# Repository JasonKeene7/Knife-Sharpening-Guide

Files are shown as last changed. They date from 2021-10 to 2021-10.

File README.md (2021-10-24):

# Knife-Sharpening-Guide
An Arduino based project to assist in keeping a consistent grinding angle.

Having recently finished building, setting up, and toubleshooting my PC, I figured starting a neew project should be my next step. Get to prevent my electronics skills from getting rusty, find all the productivity programs I need to install, and to curb my abject and growing bordem.

On the side, I was also learning my way around the kitchen which of course includes keeping all the knives sharp. Noticed they began dulling, so I took out my grindstone set hoping to rehone the edges; grind, wash, grind, wash, repeat, repeat, paper test… still made the cut, but not as smooth as I hoped and as I already done after a previous session. Huh…. Had a good, disatisfied peer down along the edge, the light just about catch the bevel’s curvature. Go figue I messed up my grinding angle, damn thing is suppoded to be flat….

“Why not make something calculate the angle for you?” rightly spoke the engineer in the back of my mind. “All I needed was to display the tilt of the knife somehow, it will be a fun warmup!”

The project lasted from the April 20th 2021 to the October 11th 2021: total project time 15 days and .72 hours.

Heads up. I am not a good essay writer, so kindly forgive any amature mistakes.

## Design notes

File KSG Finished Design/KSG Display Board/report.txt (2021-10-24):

Plot file "/run/media/jasonk/4119-0B9F/Jason Keene/Productivity/Electronics/KiCad/KSG Display Board/KSG Display Board-F_Cu.gbr" created.
Plot file "/run/media/jasonk/4119-0B9F/Jason Keene/Productivity/Electronics/KiCad/KSG Display Board/KSG Display Board-B_Cu.gbr" created.
Plot file "/run/media/jasonk/4119-0B9F/Jason Keene/Productivity/Electronics/KiCad/KSG Display Board/KSG Display Board-F_Paste.gbr" created.
Plot file "/run/media/jasonk/4119-0B9F/Jason Keene/Productivity/Electronics/KiCad/KSG Display Board/KSG Display Board-B_Paste.gbr" created.
Plot file "/run/media/jasonk/4119-0B9F/Jason Keene/Productivity/Electronics/KiCad/KSG Display Board/KSG Display Board-F_SilkS.gbr" created.
Plot file "/run/media/jasonk/4119-0B9F/Jason Keene/Productivity/Electronics/KiCad/KSG Display Board/KSG Display Board-B_SilkS.gbr" created.
Plot file "/run/media/jasonk/4119-0B9F/Jason Keene/Productivity/Electronics/KiCad/KSG Display Board/KSG Display Board-F_Mask.gbr" created.
Plot file "/run/media/jasonk/4119-0B9F/Jason Keene/Productivity/Electronics/KiCad/KSG Display Board/KSG Display Board-B_Mask.gbr" created.
Plot file "/run/media/jasonk/4119-0B9F/Jason Keene/Productivity/Electronics/KiCad/KSG Display Board/KSG Display Board-Edge_Cuts.gbr" created.
Create Gerber job file "/run/media/jasonk/4119-0B9F/Jason Keene/Productivity/Electronics/KiCad/KSG Display Board/KSG Display Board-job.gbrjob"

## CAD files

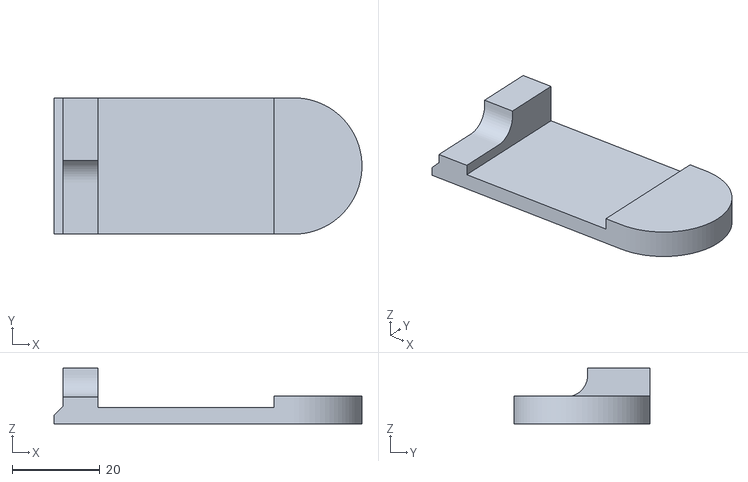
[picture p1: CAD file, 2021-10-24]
KSG Finished Design/3D Models/BNO Stand.stl
70.0 x 31.0 x 12.7

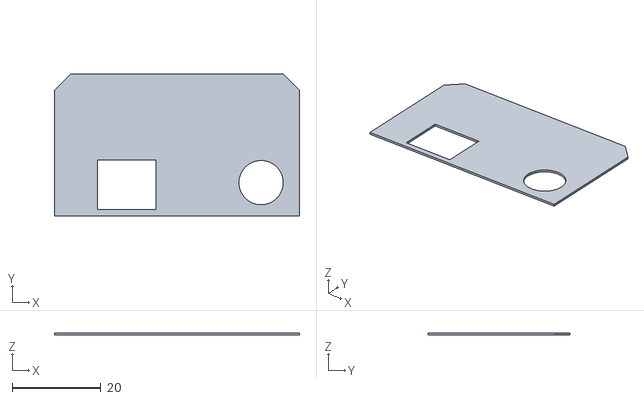
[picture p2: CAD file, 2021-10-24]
KSG Finished Design/3D Models/Power Gate.stl
55.3 x 32.0 x 0.5

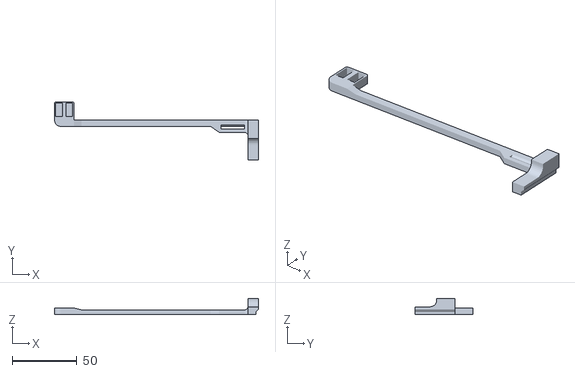
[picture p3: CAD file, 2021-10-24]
KSG Finished Design/3D Models/Clamp.stl
158.0 x 45.0 x 12.7

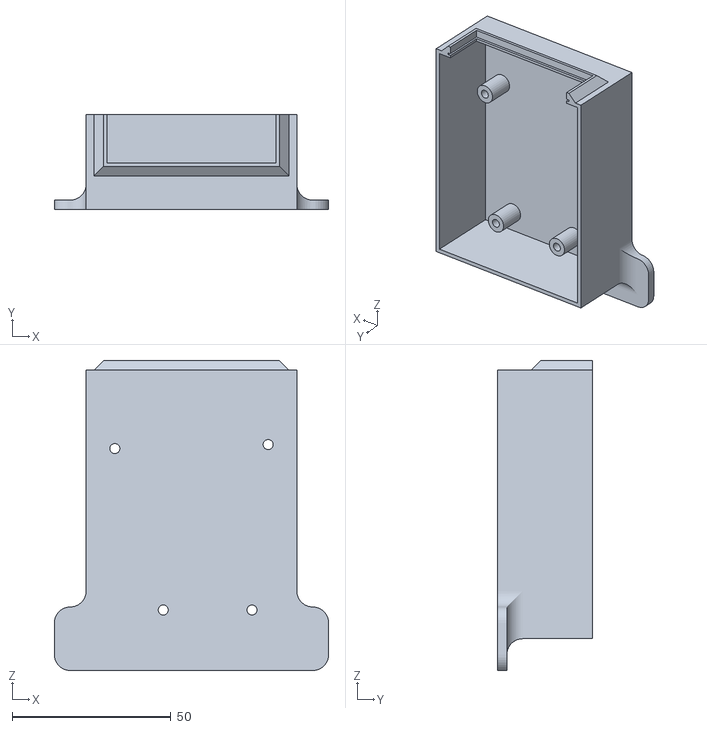
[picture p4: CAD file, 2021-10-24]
KSG Finished Design/3D Models/Case Bottom.stl
86.3 x 30.0 x 97.6

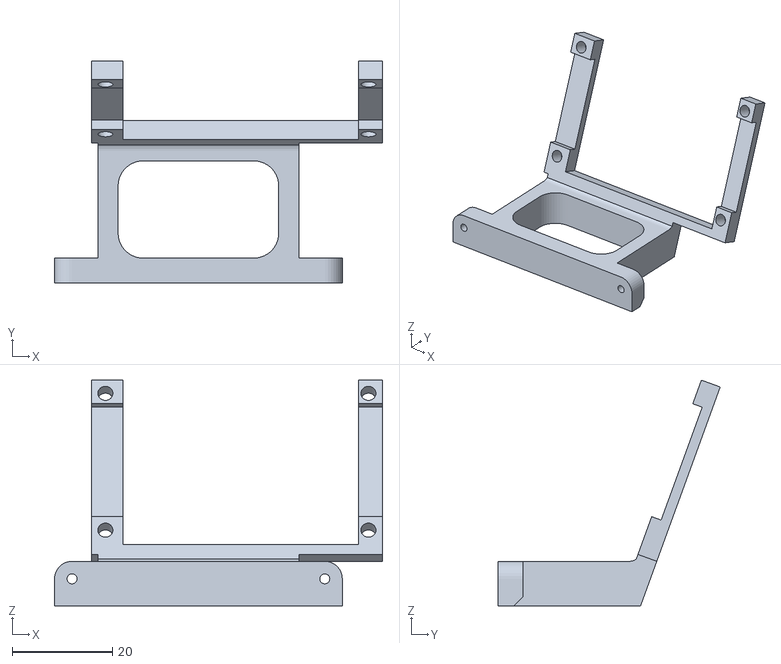
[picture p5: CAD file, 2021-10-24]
KSG Finished Design/3D Models/LCD Clamp.stl
65.3 x 44.3 x 45.0

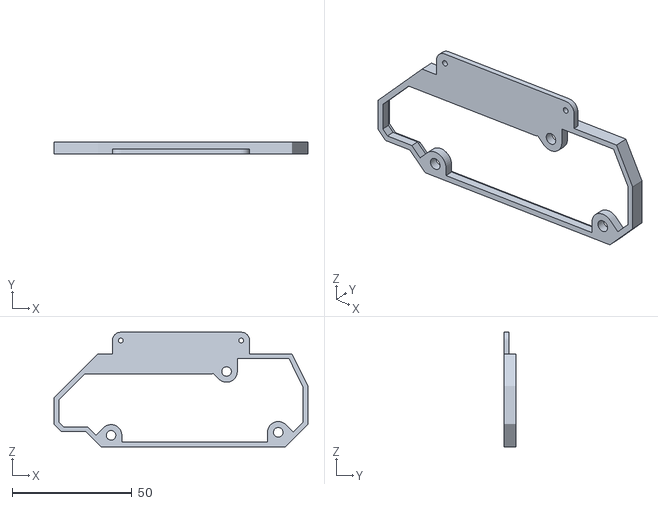
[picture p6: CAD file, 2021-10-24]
KSG Finished Design/3D Models/Control Pannel Plate.stl
106.1 x 5.00 x 47.9

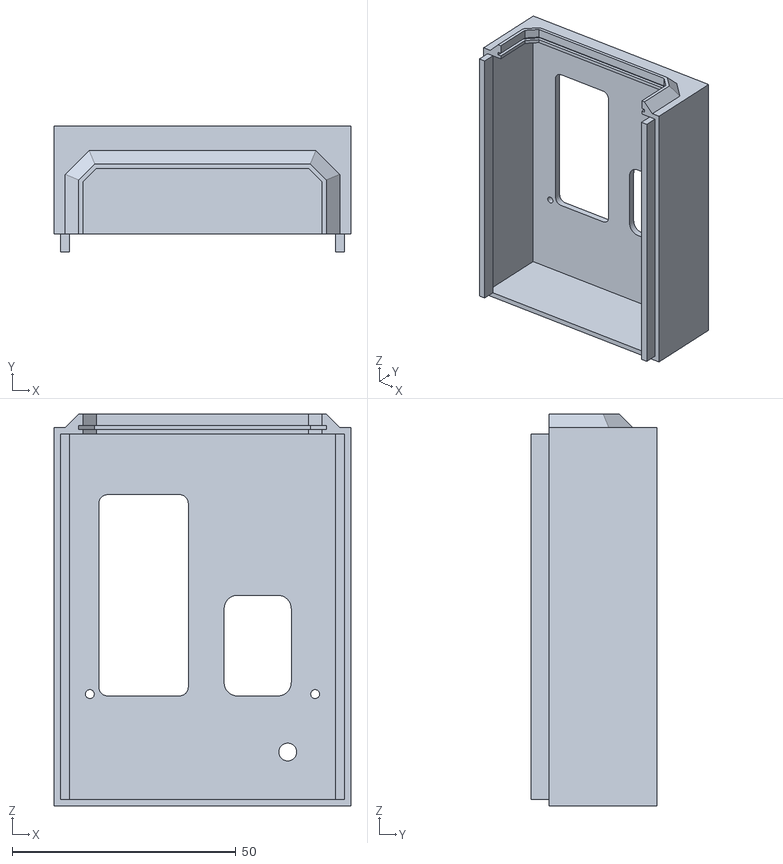
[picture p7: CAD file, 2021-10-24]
KSG Finished Design/3D Models/Case Top.stl
66.3 x 28.1 x 87.6

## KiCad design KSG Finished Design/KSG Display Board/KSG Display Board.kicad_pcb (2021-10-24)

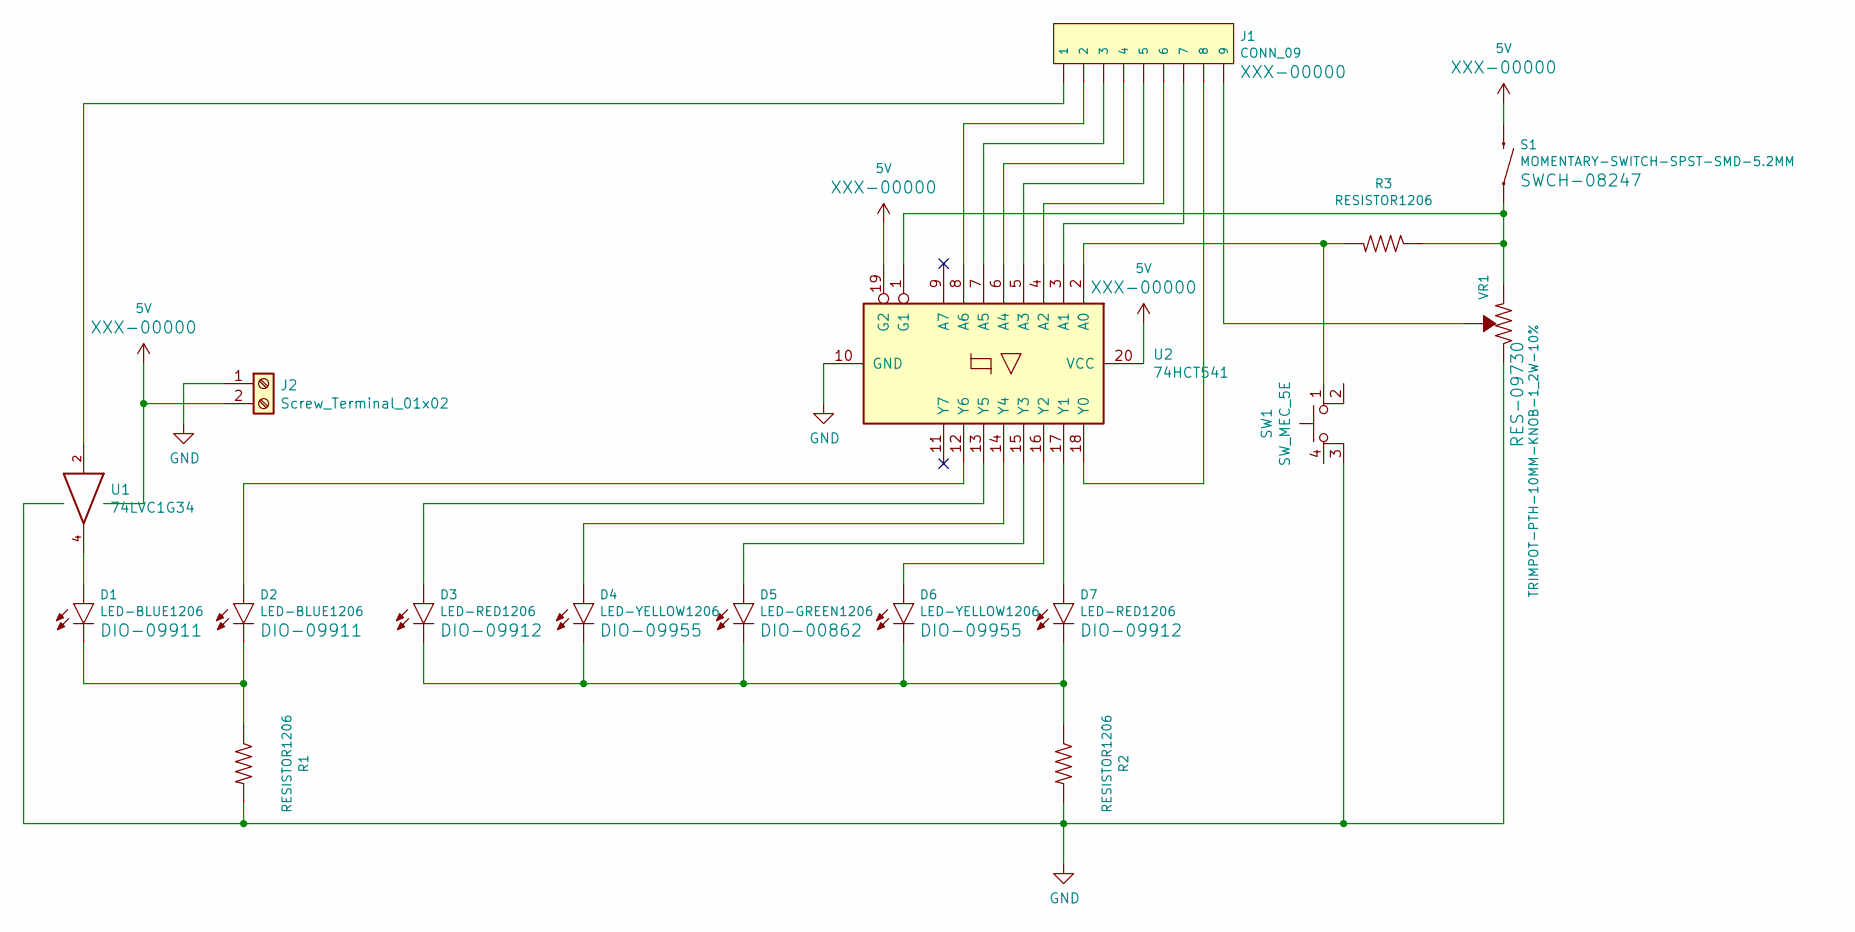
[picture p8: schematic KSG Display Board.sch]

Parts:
D1, D2: LED-BLUE1206; LED-1206
D3, D7: LED-RED1206; LED-1206
D4, D6: LED-YELLOW1206; LED-1206
D5: LED-GREEN1206; LED-1206
J1: CONN_09; 1X09
J2: Screw_Terminal_01x02; TerminalBlock_Altech_AK300-2_P5.00mm
R1, R2, R3: RESISTOR1206; 1206
S1: MOMENTARY-SWITCH-SPST-SMD-5.2MM; SPST_Switch_5.08MM
SW1: SW_MEC_5E; General_THT_Pushbutton
U1: 74LVC1G34; SOT-23-5_HandSoldering
U2: 74HCT541; SSOP-20_5.3x7.2mm_P0.65mm
VR1: TRIMPOT-PTH-10MM-KNOB-1_2W-10%; Potentiometer_Bourns_3386P_Vertical

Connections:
5V: J2.2, S1.3 (2), U1.5 (VCC), U2.19 (G2), U2.20 (VCC)
GND: J2.1, R1.2, R2.2, SW1.3 (K), U1.3 (GND), U2.10 (GND), VR1.3 (CW)
unnamed: D1.A, U1.4
unnamed: D1.C, D2.C, R1.1
unnamed: D2.A, U2.12 (Y6)
unnamed: D3.A, U2.13 (Y5)
unnamed: D3.C, D4.C, D5.C, D6.C, D7.C, R2.1
unnamed: D4.A, U2.14 (Y4)
unnamed: D5.A, U2.15 (Y3)
unnamed: D6.A, U2.16 (Y2)
unnamed: D7.A, U2.17 (Y1)
unnamed: J1.1, U1.2
unnamed: J1.2, U2.8 (A6)
unnamed: J1.3, U2.7 (A5)
unnamed: J1.4, U2.6 (A4)
unnamed: J1.5, U2.5 (A3)
unnamed: J1.6, U2.4 (A2)
unnamed: J1.7, U2.3 (A1)
unnamed: J1.8, U2.18 (Y0)
unnamed: J1.9, VR1.2 (WIPER)
unnamed: R3.1, S1.1, U2.1 (G1), VR1.1 (CCW)
unnamed: R3.2, SW1.1, U2.2 (A0)

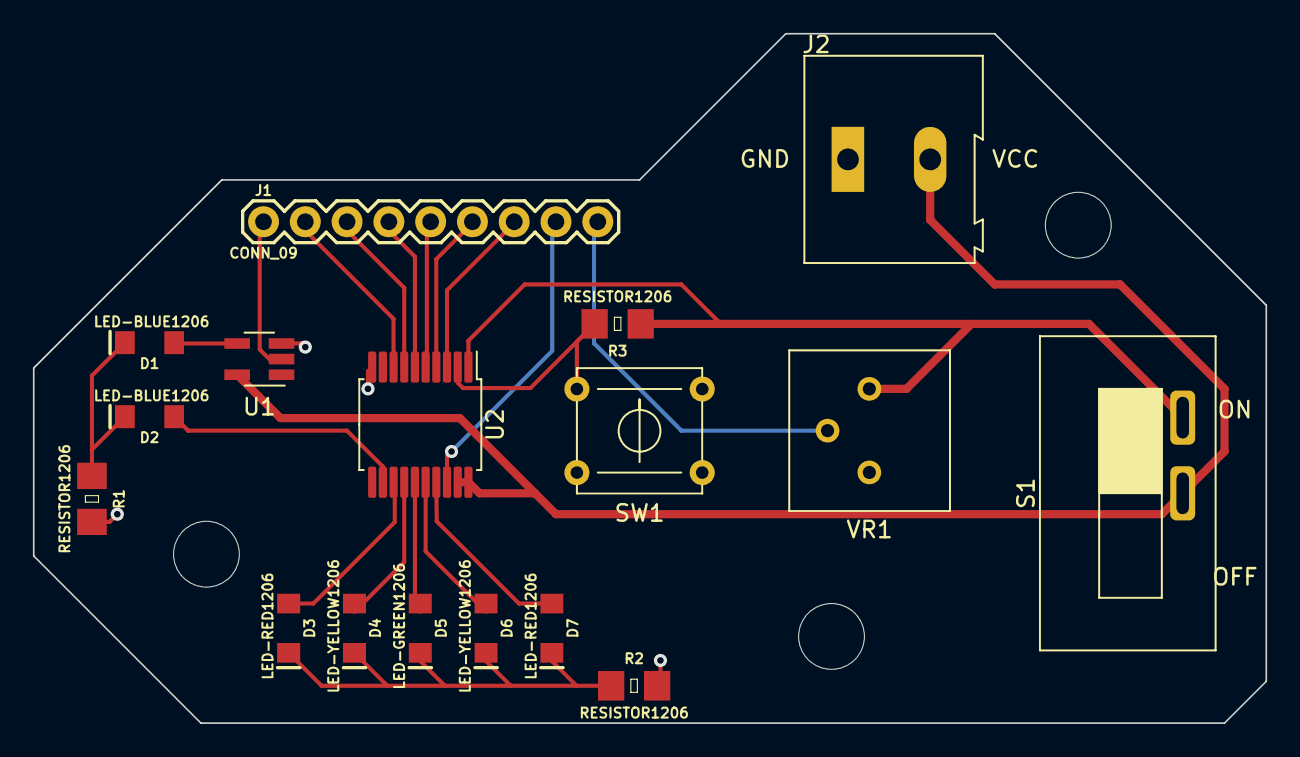
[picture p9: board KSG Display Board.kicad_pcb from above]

Board: 2 copper layers, 74.9 x 41.9 mm, 17 parts (0 on the bottom side), 22 nets.

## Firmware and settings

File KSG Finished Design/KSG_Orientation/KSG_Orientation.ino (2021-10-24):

/* 2 August, 2021
 * Thought of a better way to to find the knife angle.
 * Just use the Gyroscope:
 * With the gyroscope parallel to the knife's face and
 * assuming the person is always sharpening the edge
 * using perpendicular strokes, all that is needed would
 * be the gyroscope angle
 * 
 * TO DO: add a setup class that includes the desired knife
 * angle and calibration for the true angle of the grindstone
 */

#include "3DAngleCalc.h"

#define REFRESH_DELAY_MS    100   //Loop delay
#define SELECT              2     //Pushbutton
#define POT                 A0    //Potentiometer

angle3D calculator;

void setup() {
  delay(300);
  Serial.begin(115200);
  //while(!Serial);   //Uncomment if debuging code

  DDRD = B11111000; pinMode(POT, INPUT);
  calculator.initialize(SELECT, POT);
  delay(250);
}

void loop() {

  if(!digitalRead(SELECT)) calculator.LCD_menu();       //Pull up menu when pushbutton is pressed
  //Read BNO orientation then calculate the angle to the grindstone
  calculator.read_BNO(false); calculator.LCD_angle(calculator.get_angle(), true);
  correction(calculator.get_angle());
  delay(REFRESH_DELAY_MS);
}

//Calculate the difference between the desired and current angle
void correction(float sharpenAngle)
{
  float offBy = calculator.get_desAngle() - sharpenAngle;
  
  if(offBy < -9.0)                      PORTD = B00001000;
  else if(-9.0 < offBy && offBy < -6.0) PORTD = B00011000;
  else if(-5.0 < offBy && offBy < -3.0) PORTD = B00010000;
  else if(-3.0 < offBy && offBy < -1.0) PORTD = B00110000;
  else if(-1.0 < offBy && offBy < 1.0)  PORTD = B00100000;
  else if(1.0 < offBy && offBy < 3.0)   PORTD = B01100000;
  else if(3.0 < offBy && offBy < 6.0)   PORTD = B01000000;
  else if(6.0 < offBy && offBy < 9.0)   PORTD = B11000000;
  else if(9.0 < offBy)                  PORTD = B10000000;
}

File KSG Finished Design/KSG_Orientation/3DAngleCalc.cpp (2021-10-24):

#include "3DAngleCalc.h"

//Librearies for BNO gyroscope
#include <Wire.h>
#include <Adafruit_Sensor.h>    //Core sensor library
#include <Adafruit_BNO055.h>    //Spcific library for BNO055

//Libraries for LCD screen
#include <SPI.h>
#include <Adafruit_GFX.h>    // Core graphics library
#include <Adafruit_ST7735.h> // Specific library for ST7735
#define TFT_RST   8
#define TFT_CS    9
#define TFT_DC    10

//General library
#include <math.h>

using namespace std;

//Initialize main, LCD, and BNO objects
angle3D::angle3D():tft(TFT_CS, TFT_DC, TFT_RST), bno(55, 0x28){}

//Initialize the LCD, BNO and other settings in another method cause program would explode if it was done during setup
void angle3D::initialize(int button, int analog)
{
  SELECT = button; SWEEP = analog;  //Save input pins
  
  tft.initR(INITR_BLACKTAB);        //Init ST7735S chip, black tab
  tft.fillScreen(ST77XX_BLACK);     //Clear screen to Black
  tft.setRotation(1); LCD_text(0);  //Orient screen

  if(!bno.begin()) { LCD_text(6); while(1); }   //Check BNO connection
  
  set_angle(); calibration(); LCD_text(5);    //Initial calibrations
}

//Read the BNO055 sensor
void angle3D::read_BNO(bool flag_0)
{
  sensors_event_t level;
  bno.getEvent(&level);         //Get and save sensor values
  Radx = level.orientation.x * DtR;
  Rady = level.orientation.y * DtR;
  Radz = level.orientation.z * DtR;
  angle3D_calc(flag_0);         //Using the method parameter as both flags will always be the same
}

//Set desired angle
void angle3D::set_angle()
{
  //Convert the potentiometer input into degrees and send to another method to be displayed
  LCD_text(1);
  while(digitalRead(SELECT)) 
  {
    LCD_angle(analogRead(SWEEP)/1028.0 * 90, false);
  }
  desired_angle = analogRead(SWEEP)/1028.0 * PI/2.0;    //Convert analog to radians
  delay(CLASS_DELAY0); while(!digitalRead(SELECT));     //Make sure the button is unpressed before continuing
}

//Calibrate sensor for an unlevel grindstone
void angle3D::calibration()
{
  bool choice = false;   //Start calibration flag

  //Calibrate grindstone level if beleived not to be flat
  LCD_text(2);
  while(digitalRead(SELECT))
  {
    if(analogRead(SWEEP) < 512) { digitalWrite(5, LOW); choice = false; }
    else { digitalWrite(5, HIGH); choice = true; }
    delay(CLASS_DELAY1);
  }
  digitalWrite(5, LOW);                               //Reset LED
  delay(CLASS_DELAY1); while(!digitalRead(SELECT));   //Make sure the button is unpressed before continuing

  if(choice)
  {
    //Add wait code so BNO has time to be set
    LCD_text(3);
    while(digitalRead(SELECT));
    delay(CLASS_DELAY0); while(!digitalRead(SELECT));   //Make sure the button is unpressed before continuing

    read_BNO(true);
    LCD_text(4);

    if(dis_data)
    {
      //Display grindstone calibration
      Serial.print("\nX: ");  Serial.print(Cxyzi*RtD, 4);
      Serial.print("\tY: ");  Serial.print(Cxyzj*RtD, 4);
      Serial.print("\tZ: ");  Serial.println(Cxyzk*RtD, 4);
    }
  }
  delay(CLASS_DELAY0); while(!digitalRead(SELECT));    //Make sure the button is unpressed before continuing
}

/* Formula used to find the angle of the knife in 3D space:
 * Got the rotation vectors for the Y and Z axis and added the matrecies together:
 * the result seen in the first row of float variables, then using the angle of two 
 * planes formula to find the angle of the rotation vector and the plane of the grindstone.
 */
void angle3D::angle_2planes()
{  
  calc_angle3D =  acos((Rxyzi*Cxyzi + Rxyzj*Cxyzj + Rxyzk*Cxyzk)/
                  (pow(pow(Rxyzi,2)+pow(Rxyzj,2)+pow(Rxyzk,2),1/2)*pow(pow(Cxyzi,2)+pow(Cxyzj,2)+pow(Cxyzk,2),1/2)));
  
  if(isnan(calc_angle3D)) calc_angle3D = PI/2;    //Sets anlge to 90deg if vertical
  else if(calc_angle3D > PI/2) calc_angle3D -= 2 * (calc_angle3D - PI/2);
}

float angle3D::get_angle() { return calc_angle3D * RtD; }       //Return current angle
float angle3D::get_desAngle() { return desired_angle * RtD; }   //Return desired angle

//Calculate vector rotation
void angle3D::angle3D_calc(bool flag_cal)
{
  if(flag_cal)
  {
    //Calculate calibration vectors
    Cxyzi = cos(Radz) * cos(Rady);
    Cxyzj = sin(Radz) * cos(Radx) + cos(Radz) * sin(Rady) * sin(Radx);
    Cxyzk = sin(Radz) * sin(Radx) - cos(Radz) * sin(Rady) * cos(Radx);
  }
  else
  {
    //Calibrate knife vectors
    Rxyzi = cos(Radz) * cos(Rady);
    Rxyzj = sin(Radz) * cos(Radx) + cos(Radz) * sin(Rady) * sin(Radx);
    Rxyzk = sin(Radz) * sin(Radx) - cos(Radz) * sin(Rady) * cos(Radx);
    
    //Display the input angles
   if(dis_data)
   {
     Serial.print("\nX: ");   Serial.print(Rxyzi, 4);
     Serial.print("\tY: ");   Serial.print(Rxyzj, 4);
     Serial.print("\tZ: ");   Serial.print(Rxyzk, 4);

      uint8_t system, gyro, accel, mag;
      system = gyro = accel = mag = 0;
      bno.getCalibration(&system, &gyro, &accel, &mag);

      /* The data should be ignored until the system calibration is > 0 */
      Serial.print("\t");
      if (!system)
      {
        Serial.print("! ");
      }

      /* Display the individual values */
      Serial.print("\tSys:");   Serial.print(system, DEC);
      Serial.print(" G:");    Serial.print(gyro, DEC);
      Serial.print(" A:");    Serial.print(accel, DEC);
      Serial.print(" M:");    Serial.print(mag, DEC);
   }

    angle_2planes();
  }
}

void angle3D::LCD_angle(float dis_angle, bool flag_0)
{
  delay(CLASS_DELAY1);
  tft.fillScreen(ST77XX_BLACK);   //Clear screen to Black
  tft.setCursor(0,0);
  //Display the target angle above if set true
  if(flag_0) { tft.setTextColor(0xFFFF); tft.print("Target: "); tft.print(desired_angle * RtD); tft.println(); }
  tft.setTextColor(0xFFFF); tft.print("Angle: "); tft.print(dis_angle);   //Display current angle
}

void angle3D::LCD_text(uint8_t flag_text)
{
  delay(CLASS_DELAY1);
  tft.fillScreen(ST77XX_BLACK);   //Clear screen to Black
  tft.setCursor(0,0); tft.setTextColor(0xFFFF);
  
  switch(flag_text)
  {
    case 0: tft.println("PROGRAM START"); break;
    case 1: tft.println("Set desired angle"); break;
    case 2: tft.println("Calibrate grindstone?"); break;
    case 3: tft.println("Please set BNO on grindstone, then press button to continue."); break;
    case 4: tft.print("X: "); tft.print(Cxyzi*RtD); tft.println(" deg");
            tft.print("Y: "); tft.print(Cxyzj*RtD); tft.println(" deg");
            tft.print("Z: "); tft.print(Cxyzk*RtD); tft.println(" deg");
            break;
    case 5: tft.println("Knife calculation START"); break;
    case 6: tft.println("Ooops, no BNO055 detected ... Check your wiring or I2C ADDR!"); break;
    
    default: tft.println("Unkown flag!!!"); break;
  }
  delay(CLASS_DELAY2);
}
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
